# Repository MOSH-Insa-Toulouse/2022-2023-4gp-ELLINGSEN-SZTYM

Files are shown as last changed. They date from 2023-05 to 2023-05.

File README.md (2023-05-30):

# 2022-2023-4gp-ELLINGSEN-SZTYM

Dans le cadre de l’unité de formation “Du capteur au banc de test” suivi en 4ème année par les étudiants de Génie Physique de l’INSA de Toulouse, nous avons réalisé un capteur à jauge de contrainte low-tech à base de crayon graphite. Ce projet s’appuie sur l’ouvrage : “Pencil Drawn Strain Gauges and Chemiresistors on Paper”, écrit par : Cheng-Wei Lin, Zhibo Zhao, Jaemyung Kim & Jiaxing Huang. 

D’après cet article scientifique, le capteur créé simplement à partir de papier et d’un dépôt de crayon à papier, produirait une variation de résistance en lui appliquant une contrainte mécanique de type tension et compression. Cette variation de résistance s’explique par la variation de la distance entre les particules de graphites présentes. 

L’esprit de cette unité de formation est tournée vers l’Open Source, c’est pourquoi toutes les ressources nécessaires à la réalisation de ce projet sont disponibles dans notre dossier.  

Vous retrouverez à la suite de cette introduction, toutes les étapes de réalisation de ce projet, du design du circuit analogique à la caractérisation du capteur. 

## Sommaire

1. [Description du projet et livrables attendus](#description-du-projet-et-livrables-attendus)
2. [Matériel nécessaire](#matériel-nécessaire)
3. [Simulations sous LTSpice](#simulations-sous-ltspice)
4. [KiCad](#kicad)
   1. [Symboles, empreintes et visualisation 3D des composants](#symboles-empreintes-et-visualisation-3d-des-composants)
   2. [Schématique](#schématique)
   3. [PCB](#pcb)
   4. [Visualisation 3D](#visualisation-3d)
5. [Fabrication du Shield](#fabrication-du-shield)
6. [Arduino](#arduino)
7. [Application Bluetooth](#application-bluetooth)
8. [Tests et résultats](#tests-et-résultats)
   1. [Banc de test](#banc-de-test)
   2. [Résultats obtenus](#résultats-obtenus)
   3. [Analyse des résultats](#analyse-des-résultats)
   4. [Pistes d'améliorations](#pistes-daméliorations)
9. [Datasheet](#datasheet)
10. [Contacts](#contacts)

## Description du projet et livrables attendus

Pour atteindre les objectifs du projet, nous avons fourni plusieurs livrables :

- Des simulations sous LTSpice.
- Un schéma et un PCB modélisés avec KiCad.
- Un shield PCB
- Un code Arduino permettant de piloter le montage.
- Une application Android
- Un protocole de test et de calibration
- Une datasheet

Pour réaliser ces livrables, nous avons suivi plusieurs étapes. Tout d'abord, nous avons effectué des simulations avec le logiciel LTSpice pour vérifier que le circuit électrique fonctionnait comme prévu. Ensuite, nous avons conçu le schéma électrique et le PCB à l'aide de KiCad. Une fois le PCB imprimé, nous l'avons utilisé pour fabriquer et assembler le shield. Notre montage était connecté à une carte Arduino Uno comprenant un module Bluetooth, un écran OLED, un amplificateur transimpédance, le capteur graphite et un capteur de flexion.

Une fois le shield prêt, nous avons développé le code Arduino nécessaire pour piloter le shield, ainsi qu'une application Android permettant de récupérer les variations de résistance du capteur graphite. Ensuite, nous avons mis en place un banc de test pour caractériser le capteur de graphite avec différents types de mines (HB et B). Enfin, nous avons créé une datasheet décrivant les caractéristiques de notre capteur.

## Matériel nécessaire
- x2 résistances 100kΩ
- x2 résistances 1kΩ
- x1 résistance 10kΩ
- x1 capacité 1 μF
- x1 capacité 1 nF 
- x1 amplificateur opérationnel LTC 1050
- x1 module Bluetooth HC-05
- x1 écran OLED-2864 
- x1 flexsensor et 1 résistance de 33kΩ (en bonus)
- x1 feuille de papier et un crayon à papier

## Simulations sous LTSpice

Avant de créer le circuit imprimé, il est très utile d'utiliser le logiciel LTSpice pour effectuer des tests sur le circuit. Cela nous permet de vérifier à l'avance que le fonctionnement correspond bien à nos attentes, afin d'éviter d'éventuels problèmes ultérieurs. Nous avons réalisé des simulations du circuit, ainsi que des simulations des solutions mises en place pour une utilisation optimale de l'amplificateur, en plaçant judicieusement des filtres. Vous retrouverez toutes nos simulations ainsi qu'un rapport sur celles-ci ici : [LTSpice](https://github.com/MOSH-Insa-Toulouse/2022-2023-4gp-ELLINGSEN-SZTYM/tree/66e361c9967f16069c621319811fa84615d7094b/LTSpice). La version 17.1.8 a été utilisée.

## KiCad
Le logiciel Kicad a été essentiel dans la réalisation de schémas électriques et la modélisation de notre PCB avant la création du shield. Ce processus implique plusieurs étapes. Tout d'abord, nous avons créé les symboles et les empreintes de tous les composants que nous souhaitions incorporer, puis défini les connexions entre eux ainsi qu'avec la carte Arduino. Ensuite, nous avons édité le PCB en suivant les consignes imposées, avant de conclure par la visualisation en 3D du PCB complet. La version 6.0 de KiCad a été utilisée. 

### Symboles, empreintes et visualisation 3D des composants
Afin de réaliser le schéma du circuit, nous avons créé une librairie de symboles et d'empreintes associées pour les composants qui n'étaient pas disponibles dans les librairies intégrées au logiciel. Ensuite, nous avons établi les connexions entre les composants et la carte Arduino une fois que tous les éléments ont été schématisés.

- Capteur graphite

SCapteur

L'empreinte et le modèle 3D ont ensuite été modélisés par une résistance. 

- Flexsensor

SFlex

L'empreinte et le modèle 3D ont ensuite été modélisés par une résistance. 

- LTC1050

SLTC
ELTC
3DLTC

- Module Bluetooth

SBluetooth
EBluetooth
3DBluetooth

- Écran OLED

SOLED
EOLED
3DOLED

### Schématique

Schematic

### PCB
Ensuite, nous avons positionné les composants sur le shield et édité le circuit imprimé en répartissant les composants de manière à éviter les croisements de fils et à assurer une connexion correcte. Pour cela nous avons suivi les consignes imposées, avec des pistes de 1 mm, des pastilles de 2 mm et des zones de perçage de 0,8 mm.

PCB

### Visualisation 3D
Le téléchargement des modèles non fournis par Kicad sur le site “grabcad.com” des composants nous a permis d'obtenir un modèle 3D de notre PCB final. Cela nous a permis de vérifier que les positions des composants ne se gênaient pas mutuellement et qu'ils disposaient tous d'un espace suffisant sur le shield.

3D

## Fabrication du Shield
Grâce à l’aide de Catherine Crouzet, nous avons concrétisé le PCB physique. Il est fabriqué à partir d'une plaque d'époxy recouverte d'une fine couche de cuivre conducteur. Notre schéma de PCB, issu de Kicad, a été imprimé et utilisé comme masque lors de l'exposition aux rayons UV pour isoler la plaque. Un révélateur a été utilisé pour éliminer la résine non isolée. Ensuite, un bain de perchlorure de fer a gravé le cuivre non protégé par la résine. Ainsi, nous avons obtenu le PCB physique conforme à notre modèle Kicad.

Par la suite, nous avons percé des trous dans le PCB pour pouvoir y insérer les composants. Nous avons utilisé des trous d'un diamètre de 1 mm pour les broches de connexion de la carte Arduino, et de 0,8 mm pour les autres composants. 

Enfin, nous avons pu souder les composants sur la carte à l'aide d'étain. 

Nous obtenons le résultat suivant :

Shield

## Arduino

Le code Arduino permet d’assurer la communication entre les différents composants du PCB et la carte Arduino. 
Il permet de récupérer la valeur renvoyée par le capteur graphite, de la passer en valeur décimale et de la convertir en résistance.
Il permet aussi de récupérer la valeur renvoyée par le Flexsensor, de la convertir en valeur décimale, puis en résistance et de donner la valeur de l’angle de courbure associé.
Le tout est envoyé sur l’écran OLED grâce à la librairie Adafruit_SSD1306.h.
La valeur récupérée du capteur graphite est transférée au module Bluetooth.
La version 2.0.4 d'Arduino a été utilisée.

## Application Bluetooth

Pour capturer et visualiser les variations de résistance lors de la déformation du capteur envoyées par le module Bluetooth, nous avons développé une application Android sur la plateforme MIT App Inventor.

Notre application permet de se connecter au module Bluetooth en utilisant un bouton dédié qui affiche les périphériques disponibles localement. Une fois la connexion établie, un canvas affiche la courbe de variation de résistance en fonction du temps. En bas de l'écran, un champ de texte affiche la valeur de résistance du capteur en mégaohms. Les données sont actualisées toutes les 50 millisecondes. L'application est téléchargeable directement via un QR code crée par la plateforme. Vous pouvez retrouver l'application dans le dossier associé [Application Bluetooth](https://github.com/MOSH-Insa-Toulouse/2022-2023-4gp-ELLINGSEN-SZTYM/tree/main/Application%20Bluetooth). 

Telephone

## Tests et résultats

### Banc de test

Cylindres

La caractérisation de notre capteur a été réalisée à l’aide des cylindres présents ci-dessus. Ces 7 cylindres possèdent un diamètre de 5 cm pour le plus grand à 2 cm pour le plus petit, avec un pas de 0,5 cm entre chacun. Il est donc possible de calculer la déformation du capteur à l’aide de la formule suivante : ε = e/2R, avec e l’épaisseur de notre capteur (0.3 mm), et R le rayon de chaque cylindre. 

Il suffit de positionner le capteur graphite sur chacun des cylindres, du plus grand au plus petit et de noter la valeur renvoyée par celui-ci. Pour notre part, nous avons directement utilisé la valeur renvoyée par l’Arduino, qui est comprise entre 0 et 1024. Il est aussi nécessaire de noter la valeur renvoyée par le capteur lorsqu’il n’est soumis à aucune contrainte mécanique. 

Une fois les mesures réalisées, il est possible de tracer la variation relative de résistance du capteur graphite en fonction de la déformation appliquée. 

Nous avons tracé les courbes pour deux types de crayons différents : le HB et le B, en tension et en compression. Les valeurs en tension correspondent à la position du haut, et les valeurs en compression à la position du bas.

Tensionetcompression

### Résultats obtenus

Voici les courbes en tension et en compression obtenues pour les crayons HB et B : 

Tension
Compression

Ces tracés ont été effectués sur Jupyter Notebook (version 6.4.8).
Vous trouverez le détail de chaque courbe dans le dossier [Banc de test](https://github.com/MOSH-Insa-Toulouse/2022-2023-4gp-ELLINGSEN-SZTYM/tree/main/Banc%20de%20test).

### Analyse des résultats

En tension, le crayon HB possède un coefficient de droite de 3685,740 et le B 1290,102.
En compression, le crayon HB possède un coefficient de droite de -8298,510 et le B -3458,198.

On remarque que plus un crayon est gras, donc plus il est concentré en graphite, moins sa variation relative de résistance est élevée en valeur absolue en tension et en compression. 

De plus, sous tension, les particules de graphite s’éloignent les unes des autres, ce qui casse certains chemins de percolation et explique une augmentation de la variation de résistance. 
Sous compression, les particules de graphite se rapprochent, ce qui facilite la conduction dans le réseau percolé de notre capteur et implique une diminution de la variation relative de résistance.

Nous avons aussi caractérisé le Flexsensor en tension, afin de comparer sa sensibilité à notre capteur graphite. Voici la courbe obtenue :

Flextension

On remarque que le Flexsensor industriel possède une sensibilité plus élevée. Le coefficient directeur de sa droite est en effet beaucoup plus élevé que n’importe quel crayon que nous avons utilisé, même si nous avons forcé les droites de nos capteurs graphite à passer par 0. Il est de 69318,405. Il est donc capable de détecter des variations plus fines du signal délivré. Il est aussi beaucoup plus robuste, et son utilisation nécessite beaucoup moins de précautions que notre capteur graphite. Cependant ce Flexsensor ne permet pas la mesure de valeurs en compression. C'est un avantage que notre capteur graphite possède.

### Pistes d'améliorations

Afin d’améliorer la précision de nos courbes, nous aurions pu réaliser plus de mesures et dans de meilleures conditions. En effet, les valeurs obtenues ne sont pas très précises et sont très influencées par la quantité de graphite présente, le placement des pinces métalliques et la façon dont le capteur est courbé. Il est donc difficile d’obtenir une expérience de mesure répétable. De même, dans un esprit d'optimisation nous aurions pu utiliser moins d'espace sur notre Shield en améliorant notre routage sur KiCad. Les branchements en diagonale auraient pu être évités. 

## Datasheet

Vous trouverez la datasheet de notre capteur ici : [Datasheet](https://github.com/MOSH-Insa-Toulouse/2022-2023-4gp-ELLINGSEN-SZTYM/blob/main/Datasheet/Datasheet.pdf). Vous pouvez aussi visualiser son code LaTeX via le lien suivant : https://www.overleaf.com/read/bkwftjfrphdg.  

## Contacts

N’hésitez pas à nous contacter pour toutes questions concernant ce projet. 
- SZTYM Alice : sztym@etud.insa-toulouse.fr
- ELLINGSEN Abélia : aellings@etud.insa-toulouse.fr

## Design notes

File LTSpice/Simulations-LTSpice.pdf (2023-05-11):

## Simulations du circuit avec LTSpice

Nous devons concevoir un circuit électronique autour du capteur afin d'optimiser et d'amplifier le signal de sortie, car la tension récupérée à la sortie du capteur est très faible. En effet, la résistance du capteur est très élevée, d'environ 50 MΩ, avec une tension d'alimentation de 5V. Cela entraîne un courant de sortie du capteur d'environ 100 nA, ce qui est insuffisant pour la carte Arduino. Par conséquent, nous devons amplifier ce courant, tout en étant conscients des risques associés.

Avant de créer le circuit imprimé (PCB), il est très utile d'utiliser un logiciel tel que LTSpice pour effectuer des tests sur le circuit. Cela nous permet de vérifier à l'avance que le fonctionnement correspond bien à nos attentes, afin d'éviter d'éventuels problèmes ultérieurs. Nous avons réalisé des simulations du circuit, ainsi que des simulations des solutions mises en place pour une utilisation optimale de l'amplificateur, en plaçant judicieusement des filtres.

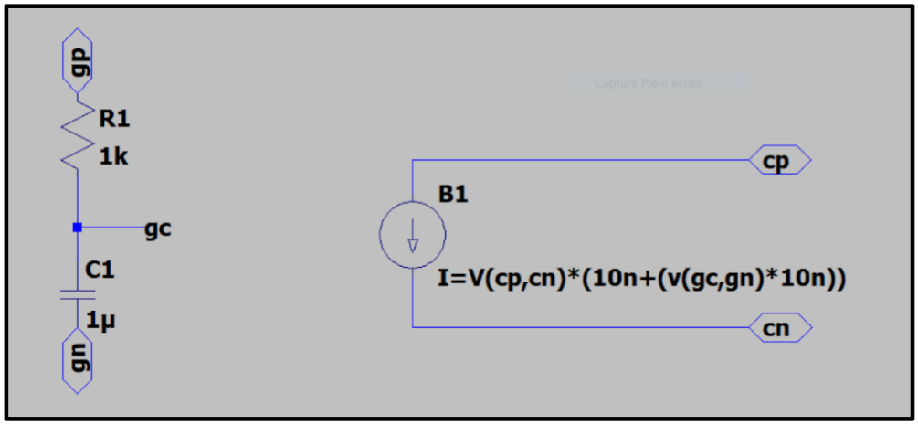
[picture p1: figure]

Figure 1 : Capteur modélisé avec LTSpice

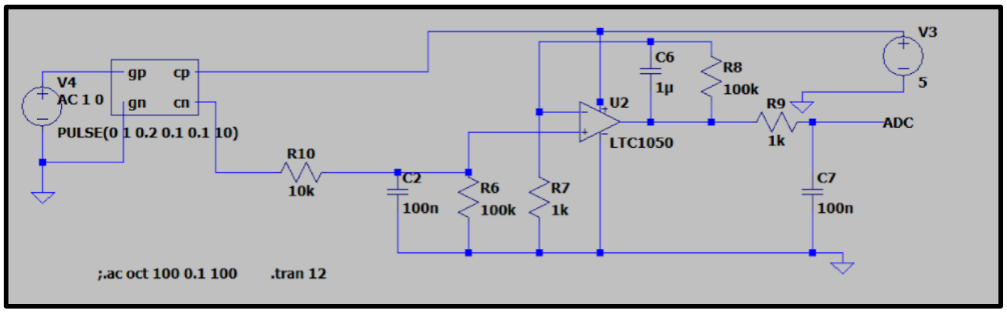
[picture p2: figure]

Figure 2 : Circuit dans lequel le capteur est intégré

### Simulation dans les conditions nominales

Nous avons effectué une simulation transitoire d'une durée de 12 secondes pour simuler le fonctionnement normal du circuit avec le capteur. L'objectif était de vérifier si le signal était correctement amplifié et dans une plage détectable par la carte Arduino. Dans la Figure 3, nous pouvons observer que la tension de sortie du montage atteint 1V, ce qui confirme sa détectabilité.

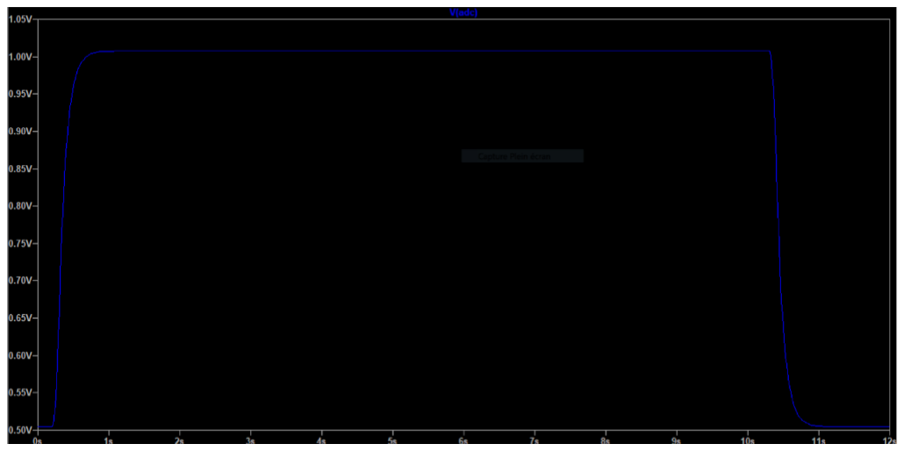
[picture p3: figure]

Figure 3 : Simulation du circuit dans les conditions nominales

### Caractérisation des filtres

Il est nécessaire d'inclure des filtres pour réduire les bruits indésirables pouvant noyer le signal utile. Nous avons utilisé trois filtres passe-bas, chacun atténuant des sources de bruit différentes. Pour les simulations de chaque filtre, nous avons activé uniquement l'étage de filtre qui nous intéressait à chaque fois, ce qui nous a permis de caractériser chaque filtre avec leurs fréquences de coupure respectives. Les simulations .ac ont été utilisées pour obtenir les diagrammes de Bode de sortie.

Filtre 1- Atténuation du bruit dû à l'alimentation du circuit, avec une fréquence de coupure de 1.6 Hz.

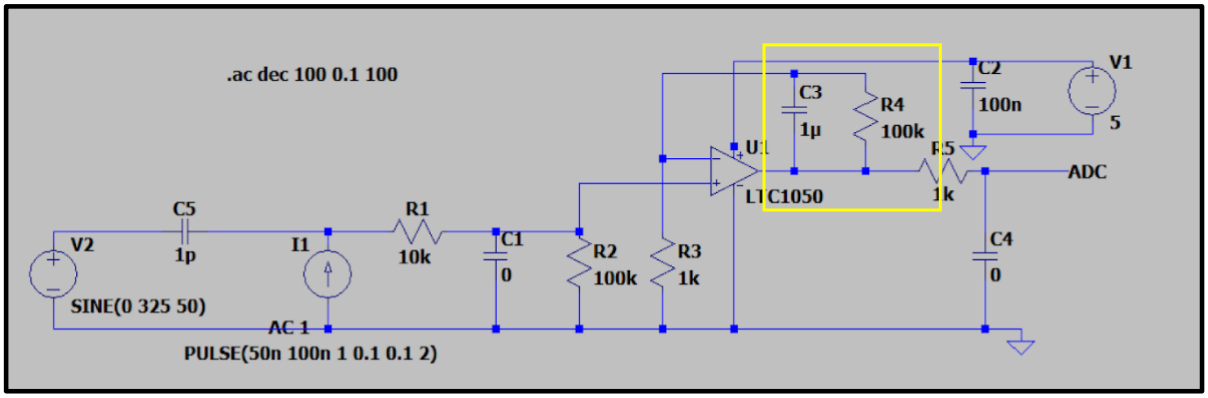
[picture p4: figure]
Figu

Figure 4 : Circuit utilisé pour la simulation du Filtre 1

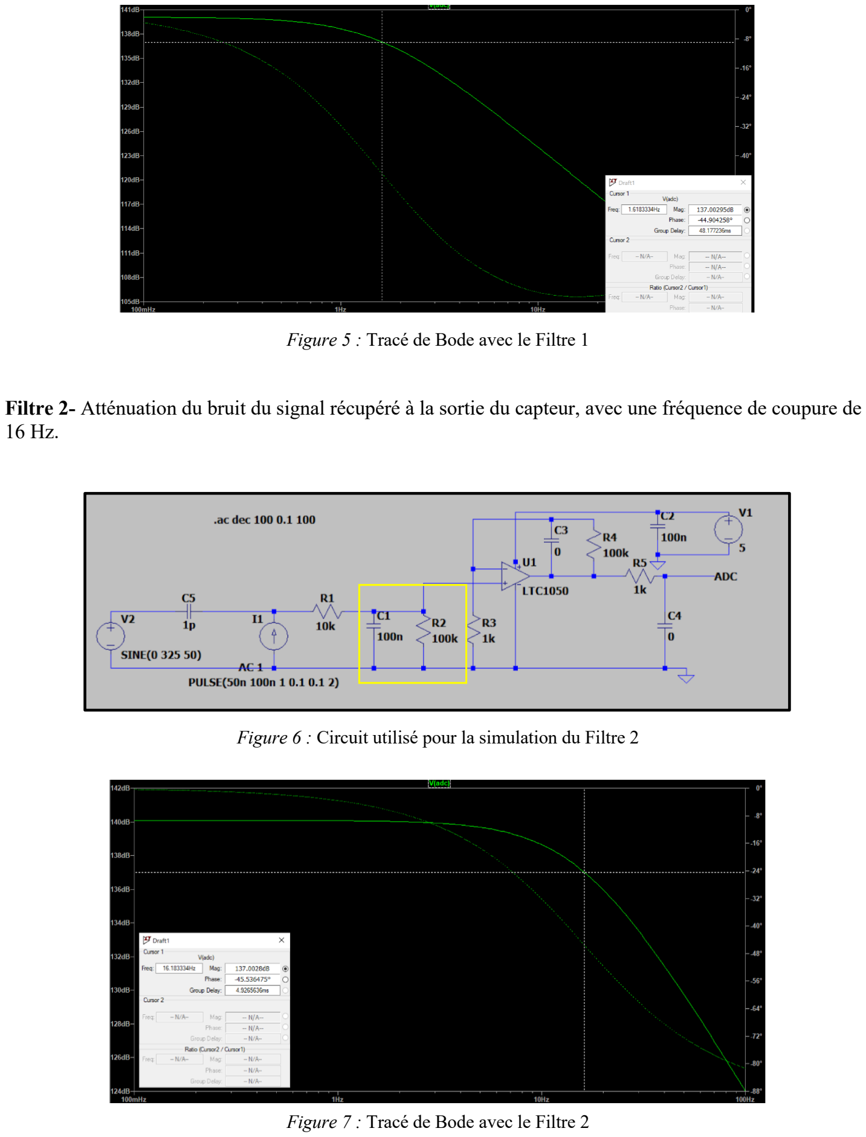
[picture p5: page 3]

Figure 5 : Tracé de Bode avec le Filtre 1

Filtre 2- Atténuation du bruit du signal récupéré à la sortie du capteur, avec une fréquence de coupure de 16 Hz.

Figure 6 : Circuit utilisé pour la simulation du Filtre 2

Figure 7 : Tracé de Bode avec le Filtre 2

Filtre 3 : Atténuation du bruit à l’entrée de l’ADC, avec une fréquence de coupure de 1.6 kHz.

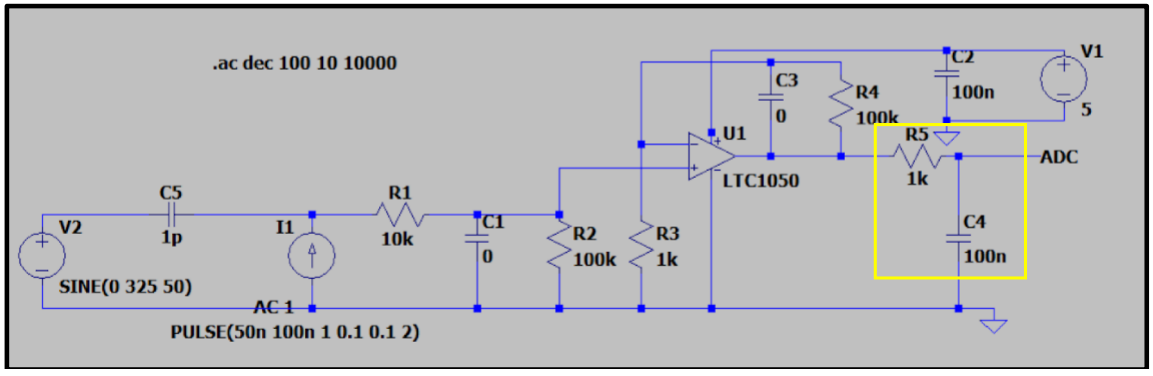
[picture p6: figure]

Figure 8 : Circuit utilisé pour la simulation du Filtre 3

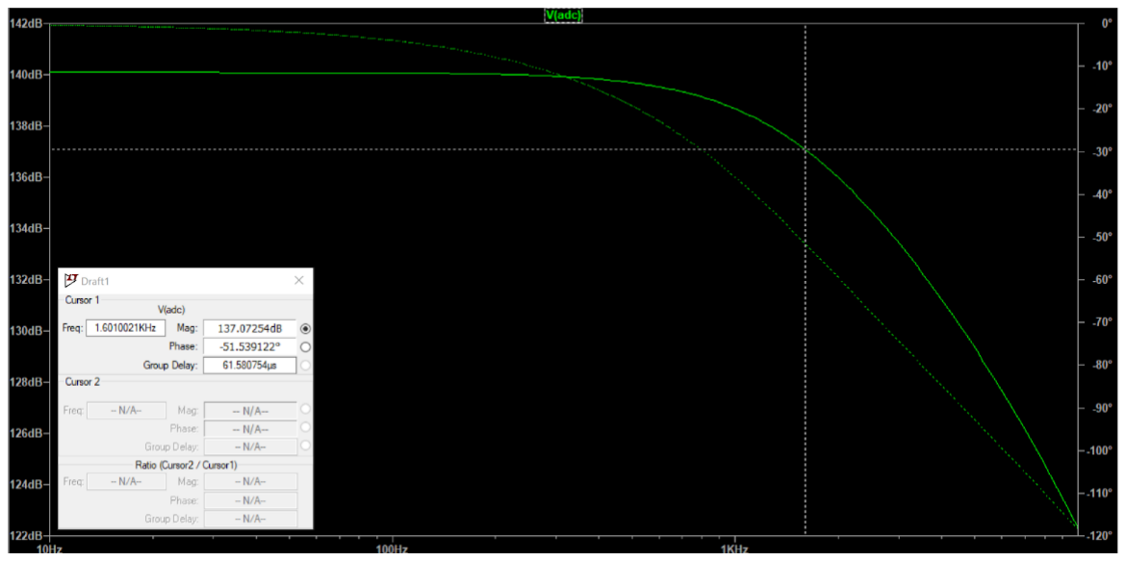
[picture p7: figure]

Figure 9 : Tracé de Bode avec le Filtre 3

### Evaluation de l’efficacité des filtres

Il est maintenant nécessaire de tester les filtres mis en place dans le montage comportant le capteur. Pour cela, il suffit d’introduire un bruit de 50 Hz représentant des interférences électriques de l'alimentation secteur. Nous réalisons ensuite une simulation en courant alternatif afin de trouver l’atténuation liée à cette fréquence, qui nous permettra de déterminer si les filtres sont efficaces ou non.

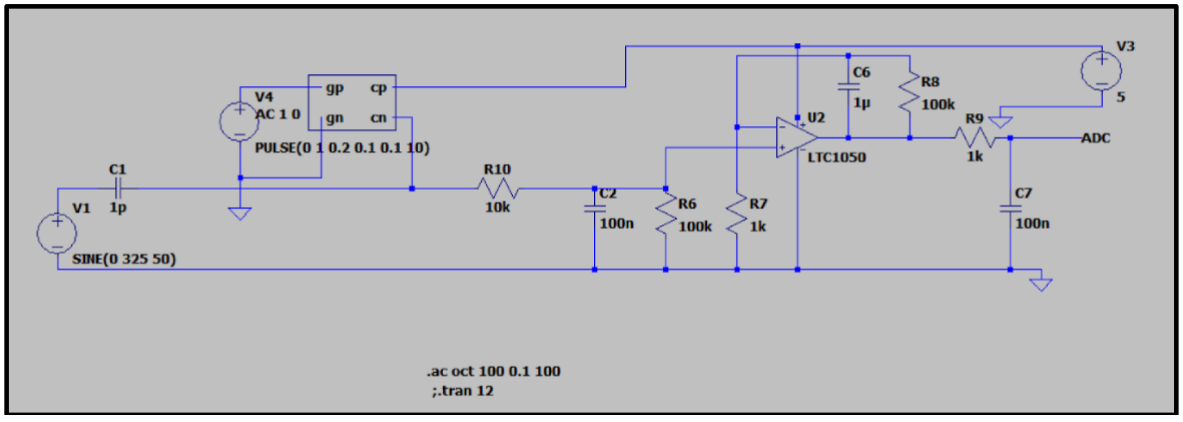
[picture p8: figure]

Figure 10 : Circuit avec tous ces filtres utilisé pour l’évaluation de l’efficacité des filtres

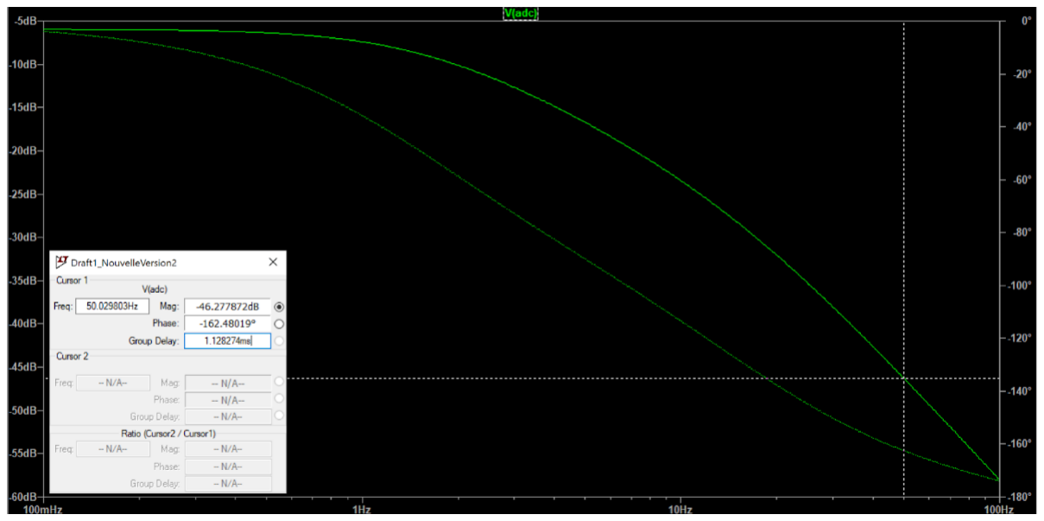
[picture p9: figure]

Figure 11 : Diagramme de Bode avec un bruit en courant de 50Hz

À 50 Hz, on obtient un gain de -46 dB, ce qui correspond à une atténuation totale de 39 dB. L’atténuation à la fréquence indésirable étant élevée, nous pouvons alors conclure que les différents filtres sont efficaces.

### La fréquence de Nyquist

Enfin, il est nécessaire de vérifier que notre montage est fonctionnel à la fréquence de Nyquist. La fréquence de Nyquist est la fréquence maximale que doit contenir un signal pour permettre sa description sans perte de qualité par un échantillonnage à intervalles réguliers. Elle est de la moitié de la fréquence d'échantillonnage. Sur une carte Arduino Uno, la plus grande fréquence d'échantillonnage utilisable possible est de 15.4 kHz. La fréquence de Nyquist est donc de 7.7 kHz. Nous simulons donc un bruit à cette fréquence, ce qui nous permettra de déterminer l’atténuation pour ce cas.

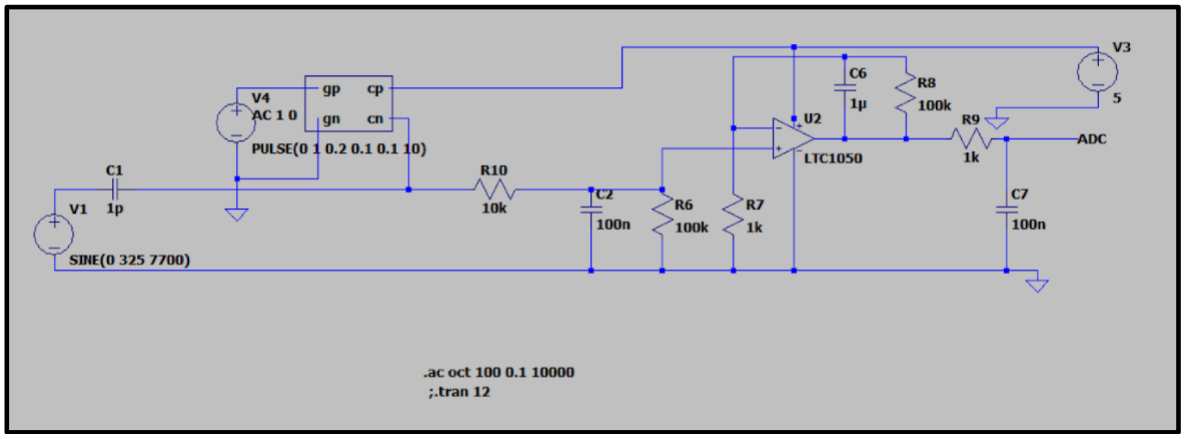
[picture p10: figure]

Figure 12 : Circuit complet utilisé pour le calcul de l’atténuation de bruit à la fréquence de Nyquist

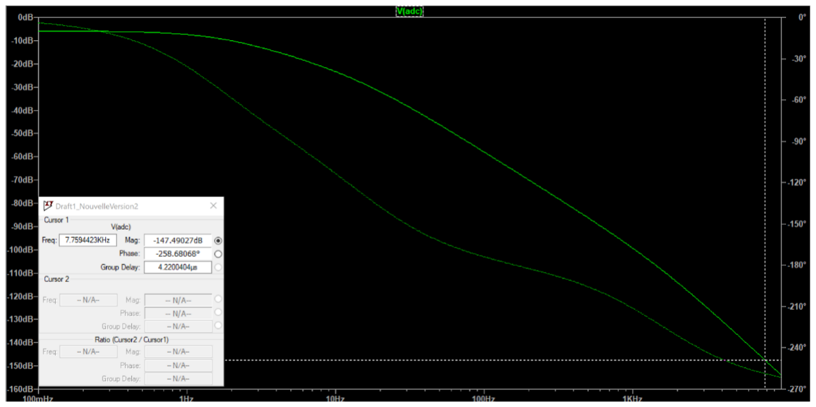
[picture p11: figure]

Figure 13 : Diagramme de Bode de la sortie avec du bruit à la fréquence de Nyquist

À partir du diagramme de Bode, nous pouvons observer une atténuation de 140 dB pour un bruit à la fréquence de Nyquist. Cette conclusion est basée sur la comparaison des gains, où nous constatons un gain de -7 dB à 0.1 Hz et un gain de -147 dB à 7.7 kHz. Ces valeurs indiquent que le bruit est complètement atténué, ce qui démontre l'efficacité de notre filtrage.

Conclusion

Les simulations effectuées avec LTSpice ont été essentielles pour caractériser chaque élément du circuit, vérifier le fonctionnement de chaque partie et évaluer les performances globales du système. Elles nous ont permis de valider les choix de conception, d'optimiser les paramètres des filtres et d'assurer que le signal utile était amplifié de manière adéquate.

Maintenant que nous avons validé le concept et le fonctionnement de notre circuit, nous sommes prêts à passer à la prochaine étape, qui consiste à concevoir et réaliser le PCB qui mettra en œuvre l'ensemble des composants et connexions de manière optimale.

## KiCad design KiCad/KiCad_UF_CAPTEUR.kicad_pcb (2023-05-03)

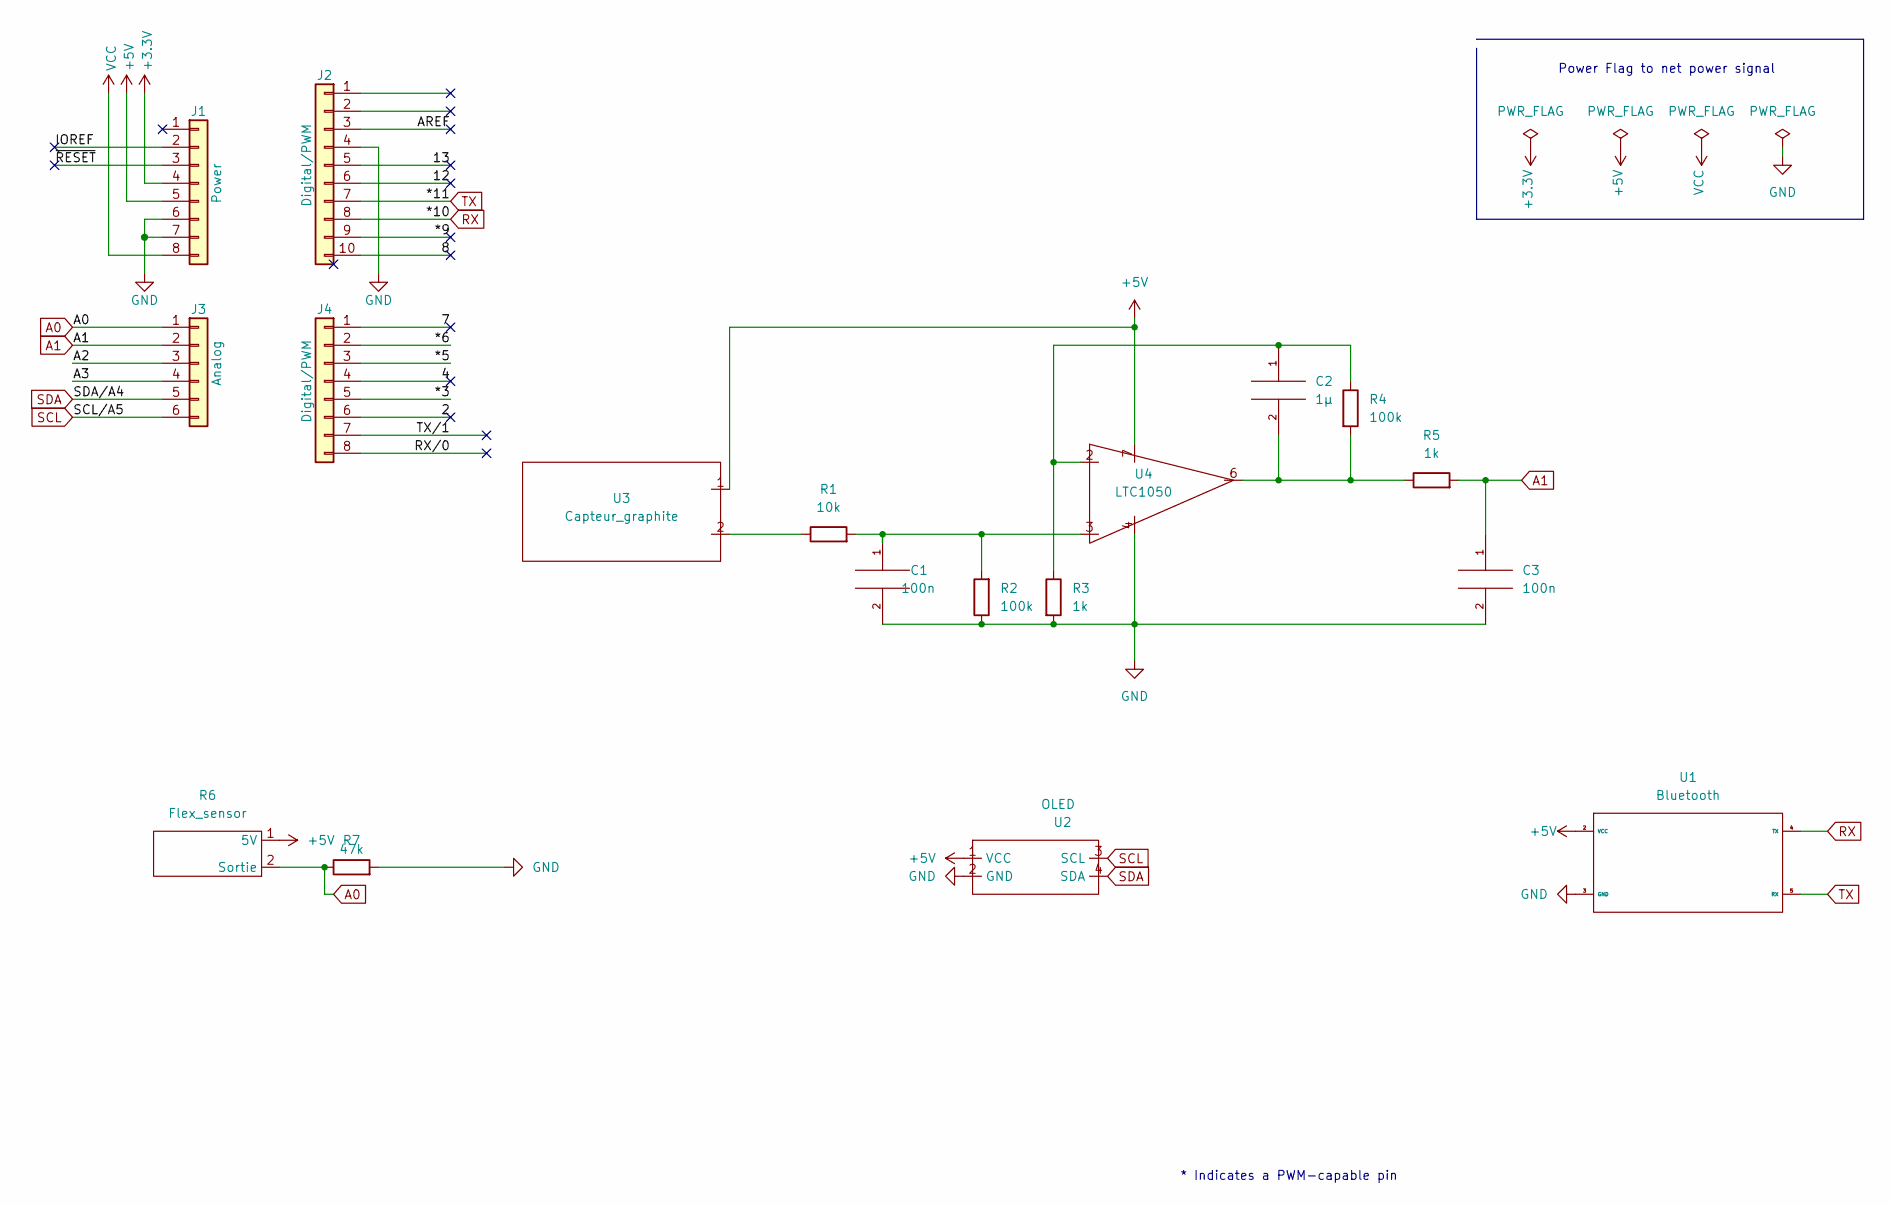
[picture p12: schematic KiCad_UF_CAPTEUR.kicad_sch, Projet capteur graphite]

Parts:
C1, C3: 100n; C_Disc_D4.7mm_W2.5mm_P5.00mm
C2: 1µ; C_Rect_L7.0mm_W4.5mm_P5.00mm
J1: Power; PinSocket_1x08_P2.54mm_Vertical
J2: Digital/PWM; PinSocket_1x10_P2.54mm_Vertical
J3: Analog; PinSocket_1x06_P2.54mm_Vertical
J4: Digital/PWM; PinSocket_1x08_P2.54mm_Vertical
R1: 10k; R_Axial_DIN0204_L3.6mm_D1.6mm_P5.08mm_Vertical
R2, R4: 100k; R_Axial_DIN0204_L3.6mm_D1.6mm_P5.08mm_Vertical
R3, R5: 1k; R_Axial_DIN0204_L3.6mm_D1.6mm_P5.08mm_Vertical
R6: Flex_sensor; PinHeader_1x02_P2.54mm_Vertical
R7: 47k; R_Axial_DIN0204_L3.6mm_D1.6mm_P5.08mm_Vertical
U1: Bluetooth; R_Array_SIP6
U2: OLED; SIP-4
U3: Capteur_graphite; R_Axial_DIN0204_L3.6mm_D1.6mm_P5.08mm_Vertical
U4: LTC1050; DIP-8_W7.62mm_LongPads

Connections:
+3V3: J1.4
+5V: J1.5, R6.1 (5V), U1.2 (VCC), U2.1 (VCC), U3.1, U4.7
/2: J4.6
/4: J4.4
/7: J4.1
/8: J2.10
/12: J2.6
/13: J2.5
/*3: J4.5
/*5: J4.3
/*6: J4.2
/*9: J2.9
/A2: J3.3
/A3: J3.4
/AREF: J2.3
/IOREF: J1.2
/RX/0: J4.8
/TX/1: J4.7
/~RESET: J1.3
A0: J3.1, R6.2 (Sortie), R7.1
A1: C3.1, J3.2, R5.2
GND: C1.2, C3.2, J1.6, J1.7, J2.4, R2.1, R3.2, R7.2, U1.3 (GND), U2.2 (GND), U4.4
unnamed: C1.1, R1.2, R2.2, U4.3
unnamed: C2.1, R3.1, R4.1, U4.2
unnamed: C2.2, R4.2, R5.1, U4.6
unnamed: R1.1, U3.2
RX: J2.8, U1.4 (TX)
SCL: J3.6, U2.3 (SCL)
SDA: J3.5, U2.4 (SDA)
TX: J2.7, U1.5 (RX)
VCC: J1.8

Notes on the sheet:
Power Flag to net power signal
* Indicates a PWM-capable pin

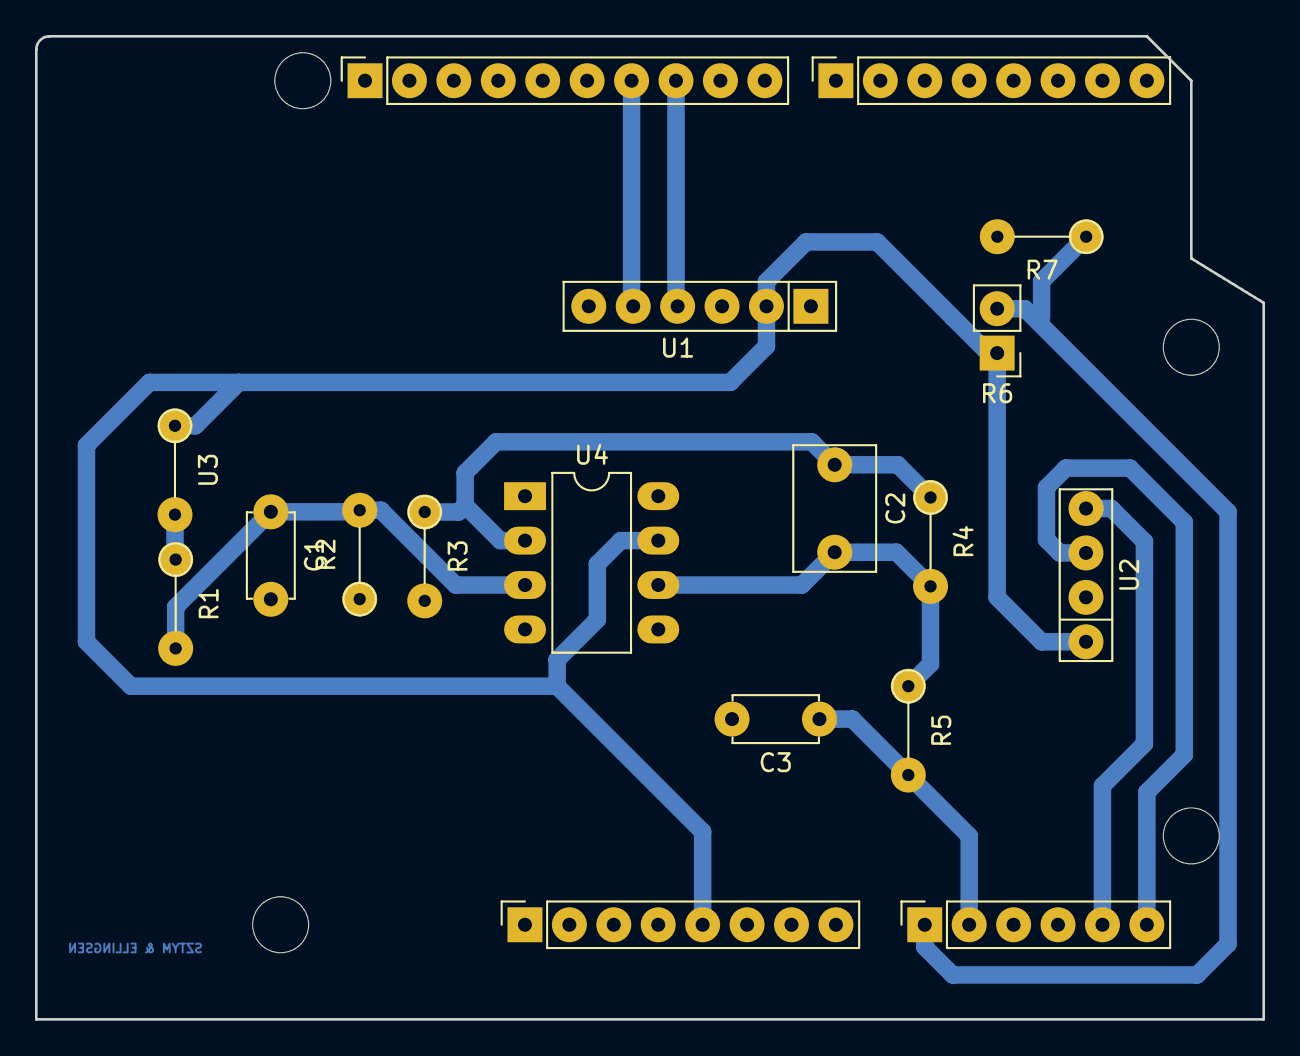
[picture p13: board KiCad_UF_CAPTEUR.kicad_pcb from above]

Board: 2 copper layers, 70.2 x 56.2 mm, 22 parts (0 on the bottom side), 12 nets.

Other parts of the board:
MH1, MH2, MH3, MH4: MountingHole_3.2mm

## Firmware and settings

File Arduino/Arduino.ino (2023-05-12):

/*
  Fichier : Arduino      
  Description :  Code Arduino pour notre projet capteur de 4A GP 
  Auteur : ELLINGSEN Abélia & SZTYM Alice       
  Créé le : Mai 2023       
*/

//Définitions et librairies relatives à l'OLED
#include <Adafruit_SSD1306.h>

#define nombreDePixelsEnLargeur 128         // Taille de l'écran OLED, en pixel, au niveau de sa largeur
#define nombreDePixelsEnHauteur 64          // Taille de l'écran OLED, en pixel, au niveau de sa hauteur
#define brocheResetOLED         -1          // Reset de l'OLED partagé avec l'Arduino (d'où la valeur à -1, et non un numéro de pin)
#define adresseI2CecranOLED     0x3C        // Adresse de "mon" écran OLED sur le bus i2c (généralement égal à 0x3C ou 0x3D)

Adafruit_SSD1306 ecranOLED(nombreDePixelsEnLargeur, nombreDePixelsEnHauteur, &Wire, brocheResetOLED);


#define Periode 50 //envoie des données toutes les 50ms


// Constantes relatives au flex sensor
const int flexPin = A0;      // Pin utilisé pour récupérer le signal
const float VCC = 5;      // VCC de l'Arduino
const float R_DIV = 33000.0;  // Résistance utilisée pour créer un pont diviseur de tension 
const float flatResistance = 33000.0; // Résistance avec capteur plat
const float bendResistance = 77000.0;  // Résistance avec le capteur à 90 degrés

float sensorValue ;
float sensorValue_ard ;
float resistance ;

// Définitions et librairies relatives au module Bluetooth
#include <SoftwareSerial.h>
#define rxPin 10
#define txPin 11

SoftwareSerial mySerial(rxPin ,txPin); //Définition du software serial
unsigned long temps_ref=0;

void setup() {

  // Initialisation de l'écran OLED
  if(!ecranOLED.begin(SSD1306_SWITCHCAPVCC, adresseI2CecranOLED))
    while(1);    // Arrêt du programme (boucle infinie) si échec d'initialisation

  pinMode(flexPin, INPUT);
  pinMode(rxPin,INPUT);
  pinMode(txPin,OUTPUT);

  Serial.begin(9600);
  mySerial.begin(9600);
}

void loop() {
    
  // Lecture de la valeur du capteur graphite et conversion en résistance
  sensorValue_ard = analogRead(A1);
  sensorValue=sensorValue_ard*5/1024; //Tension sur 5 volt et 10 bits
  resistance = (1.0+100.0)*100000.0*(5.0/sensorValue)-100000.0-10000.0;
  //Serial.println(resistance);
  //Serial.println(sensorValue);  

  // Lecture et conversion du signal en résistance délivré par le flex sensor
  int ADCflex = analogRead(flexPin);
  float Vflex = ADCflex * VCC / 1023.0;
  float Rflex = R_DIV * (VCC / Vflex - 1.0);
  //Serial.println("Resistance: " + String(Rflex) + " ohms");

  // Estimation de l'angle du flex sensor 
  float angle = map(Rflex, flatResistance, bendResistance, 0, 90.0);
  //Serial.println("Bend: " + String(angle) + " degrees");

 // Affichage sur l'écran OLED
  byte tailleDeCaractere=1 ;
  
  ecranOLED.clearDisplay(); 
  ecranOLED.setTextSize(tailleDeCaractere); // Taille des caractères (1:1)
  ecranOLED.setCursor(0, 0); // Déplacement du curseur en position (0,0), c'est à dire dans l'angle supérieur gauche
  ecranOLED.setTextColor(SSD1306_WHITE); // Affichage du texte en "blanc"
 
  ecranOLED.println("Resistance capteur graphite : " + String(resistance/1e6) + " MOhms"); 
  
  ecranOLED.println("Resistance flexsensor : " + String(Rflex) + " ohms"); 
  ecranOLED.println("Angle: " + String(angle) + " degrees");
          
  ecranOLED.display(); // Transfert le buffer à l'écran

//Transfert auBluetooth  
if (abs(millis()-temps_ref) > Periode)
 { 
  temps_ref=millis();
 byte V = map(sensorValue_ard,0,1023,0,255);
 mySerial.write(V);
 }
 
 delay(25);

}
